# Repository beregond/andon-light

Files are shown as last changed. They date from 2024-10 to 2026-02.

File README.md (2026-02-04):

# ())))) Andon Light

Signal state with andon light!

## Docs

This document is not everything you need to know about this project, more info below in "More docs" section

> [!WARNING]
> This project is still in early development stage, so it may not work as expected.

> [!WARNING]
> If you experience lag during startup it means that either you don't have SD card inserted (with proper config) - and thats due to bug, or your power source is too weak (especially if you enable WiFi this may be the problem)

## How does it work?

Andon light is a tool for monitoring external device and signaling its state using lights and sounds.

> [!NOTE]
> Currently only configuration for TCS3472 sensor and Prusa mk4 is available. More configurations will be (hopefully) added in the future.

There are two basic components:

- **Device** - something we want to monitor, like 3d printer; state of device is read by sensor
- **System** - andon light itself.

Both of them have their statuses and below you can see how those statuses are mapped to patterns, colors and sounds.

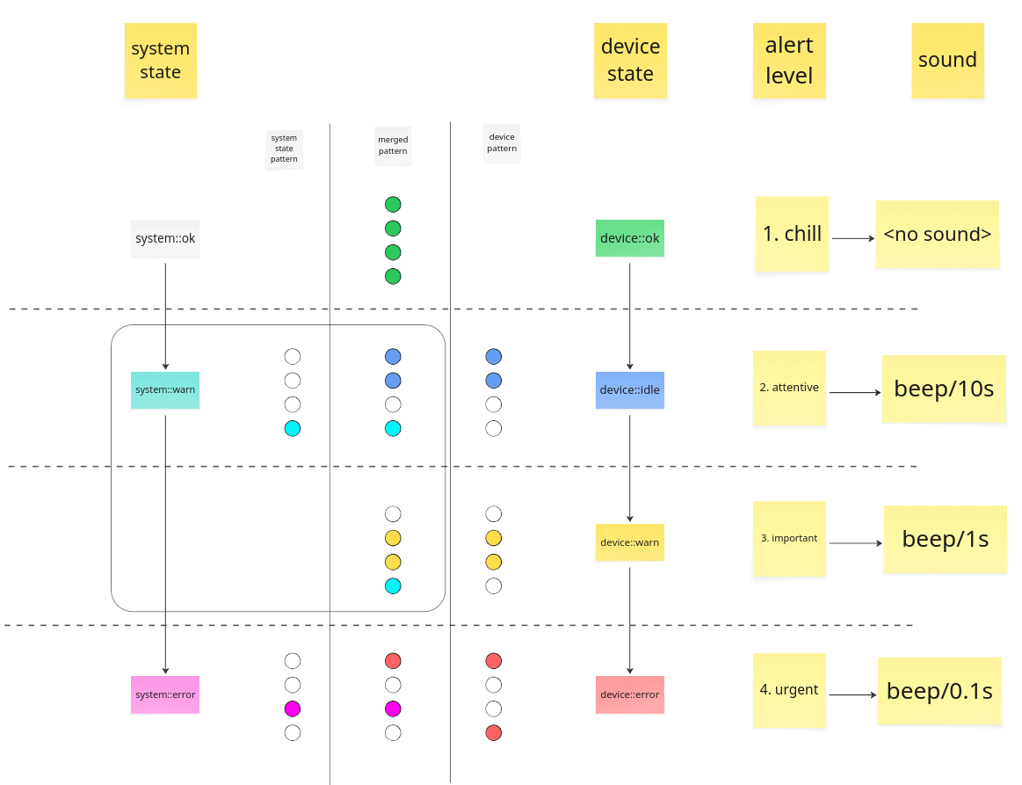
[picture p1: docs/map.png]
Patterns mapping


The algorithm works like this:

- Take the **highest** corresponding alert level from the **sensor and system state**
- Using patterns from that alert level, choose:
  - Pattern that matches both of the states
  - If no such pattern exists, choose the one that matches either of the states
- Choose sound that matches alert level

## Config

Store this in `andon.jso`. Currently there is no support for long file names (aka VFAT).

``` json
{
    "version": 0,
    "id": "my-3d-printer",
    "brightness": 10,
    "buzzer_enabled": true,

    "wifi_ssid": "your-ssid",
    "wifi_password": "your-password",

    "mqtt_host": "mqtt.example.com",
    "mqtt_port": 1883,
    "mqtt_username": "your-username",
    "mqtt_password": "your-password",
    "mqtt_device_type": "cnc",
    "mqtt_topic_prefix": "andon",
    "mqtt_topic": "your/custiom/topic"
}
```

### Config reference

- `id` - unique identifier of the device, it will default to `light-{MAC_ADDRESS}` if not set
- WiFi settings are optional, but required for MQTT
- MQTT section is optional, will work only with WiFi enabled
- `mqtt_username` - don't set for anonymous connection
- `mqtt_password` don't set for anonymous connection
- `mqtt_device_type` - `cnc` by default, used for mqtt topic construction, skipped if `mqtt_topic` is set
- `mqtt_topic_prefix` - `andon` by default, used for topic construction, skipped if `mqtt_topic` is set
- `mqtt_topic` - `null` by default, if not set - topic will be constructed using prefix, device type and id

## More docs

- To see the list of parts needed to build this project, check [this file](docs/parts.md).
- You will need few 3D printed parts, to print them follow [this guide](3d-models/readme.md).

## Development

List `devbin` dir to see available helpful commands

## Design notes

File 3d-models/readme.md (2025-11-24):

# 3d printed parts

**Use .step files as first choice**. All parts were printed with (Prusa MK4S printer and):

- standard black PLA
- 0.4mm nozzle
  - 0.15 layer height for shell in quality/structural mode (to print inner threads properly)
  - 0.2mm layer height for rest of parts (in speed mode)
- 15% infill (gyroid, but thats secondary)

Most of parts you should print in default orientation, unless stated otherwise. Below you can see extra settings for each part.

## Tower

Print it vertically. Supports are required, but avoid putting them in tight spaces inside (see picture below).

- [step](tower/tower.step)
- [3mf](tower/tower.3mf)
- [stl](tower/tower.stl)

Preview

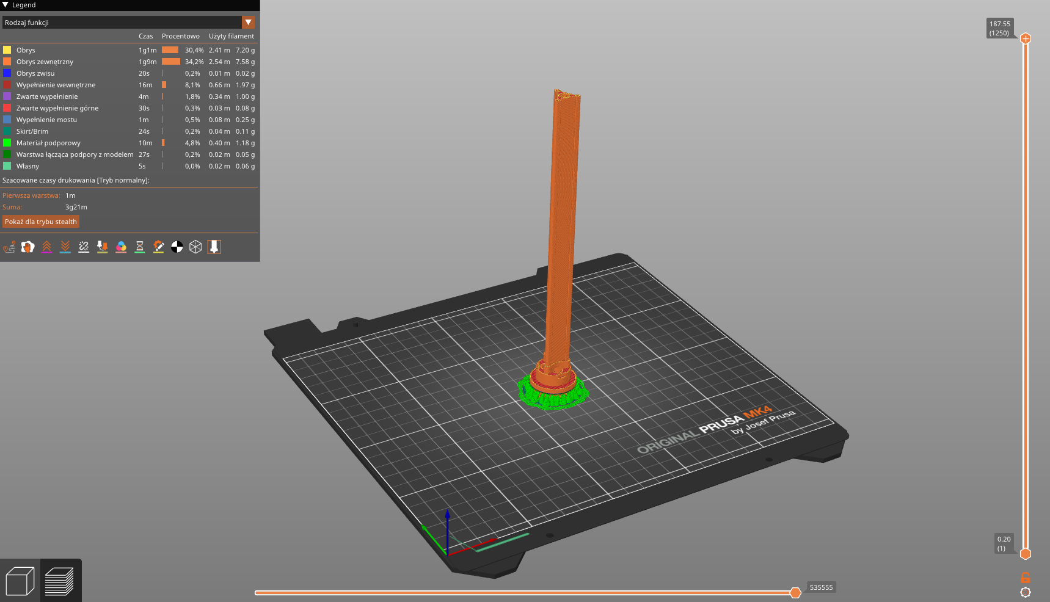
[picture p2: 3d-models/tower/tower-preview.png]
Tower print preview


### Where to avoid supports

You don't want to put supports between PCB holds and in the middle of the tower - only have them for flat overhangs outside and inside the tower.

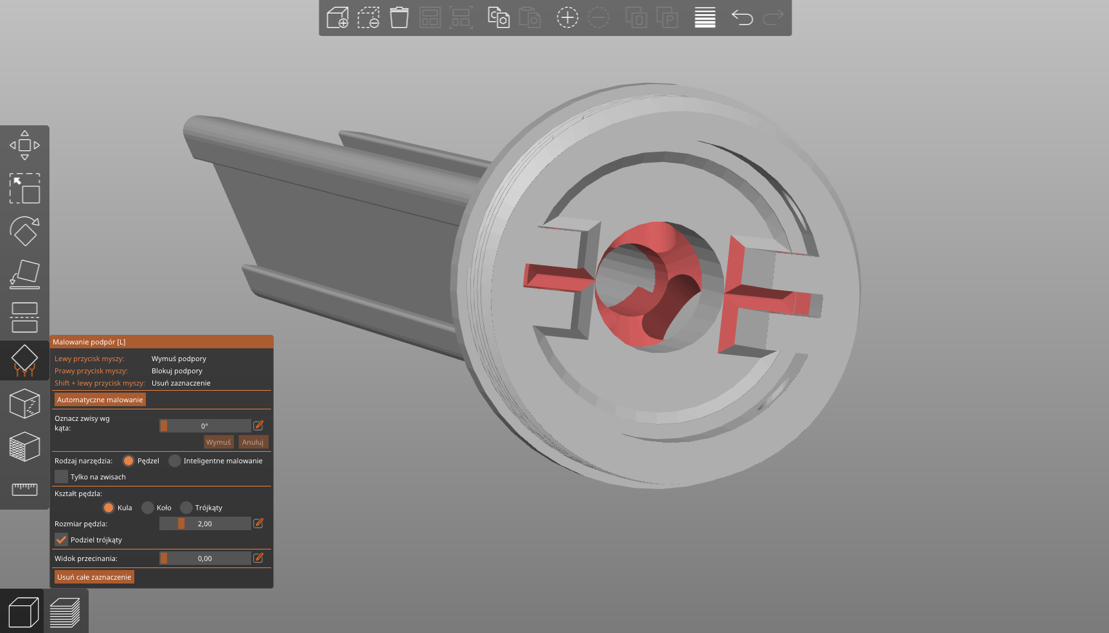
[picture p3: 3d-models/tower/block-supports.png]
Block supports


## Shell

Quality/structural mode is **required** to print threads properly (like 0.15 layer height in structural mode), 5mm inner brim is **recommended** (you can scrape it off with deburring tool easily).

- [step](shell/shell.step)
- [3mf](shell/shell.3mf)
- [stl](shell/shell.stl)

Preview

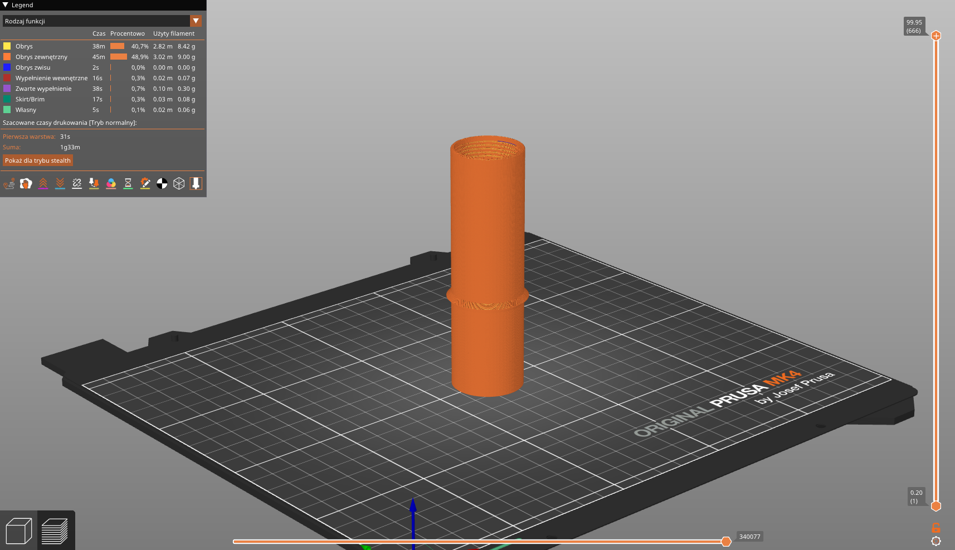
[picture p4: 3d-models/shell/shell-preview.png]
Shell print preview


## Hood

Print this part upside down, so you don't need supports.

- [step](hood/hood.step)
- [3mf](hood/hood.3mf)
- [stl](hood/hood.stl)

Preview

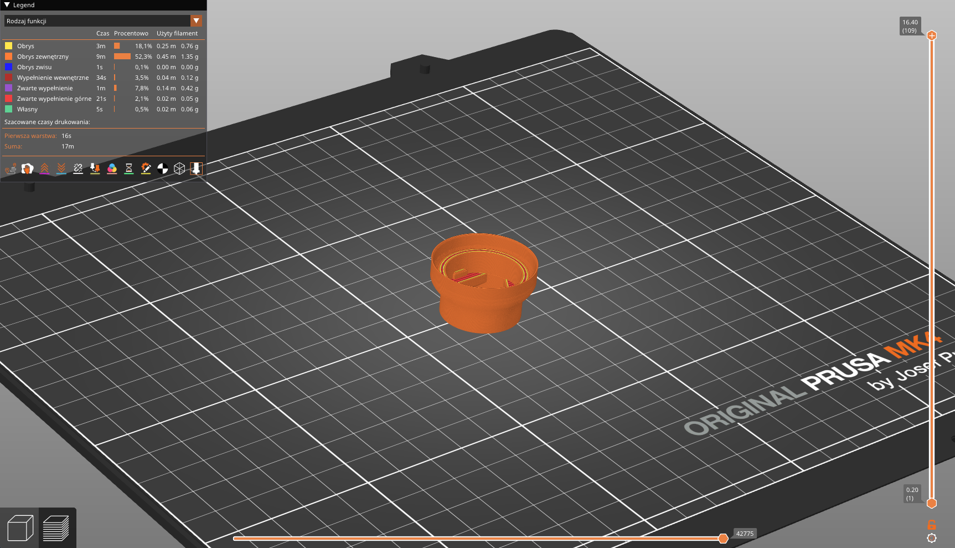
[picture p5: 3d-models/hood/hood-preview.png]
Hood print preview


## cap

Top cap for the tower. Print it with supports.

- [step](cap/cap.3mf)
- [3mf](cap/cap.3mf)
- [stl](cap/cap.stl)

Preview

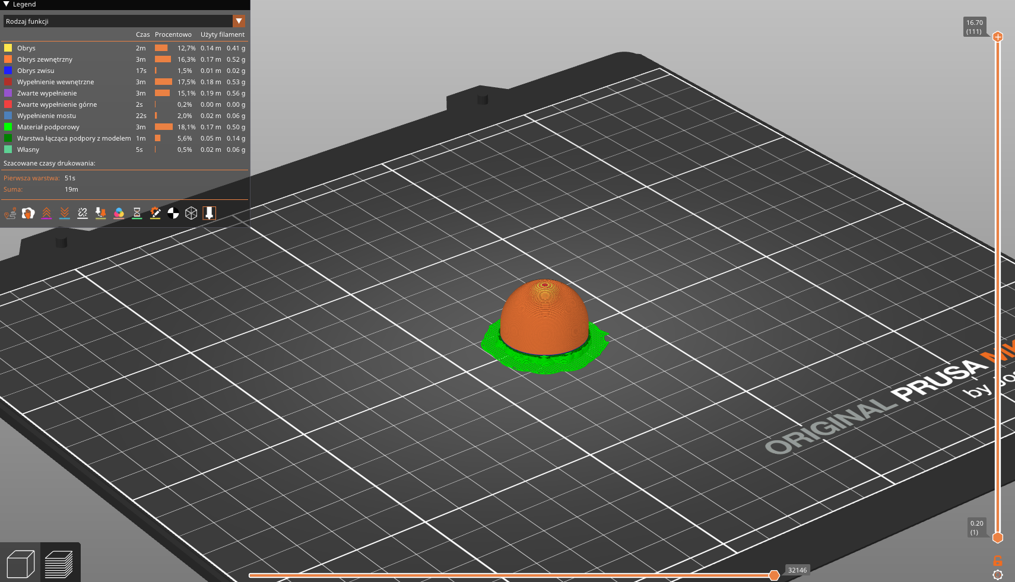
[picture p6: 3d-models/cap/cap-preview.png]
Cap print preview


## Bottom Cap

- [step](bottom-cap/bottom-cap.step)
- [3mf](bottom-cap/bottom-cap.3mf)
- [stl](bottom-cap/bottom-cap.stl)

Preview

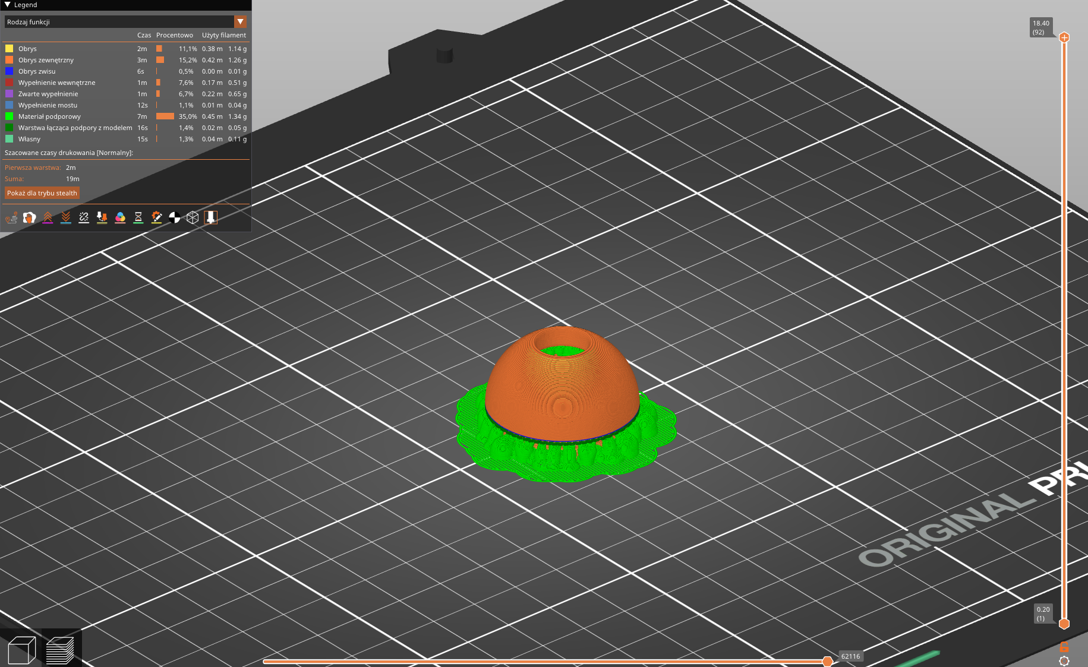
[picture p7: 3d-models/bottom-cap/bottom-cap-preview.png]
Bottom cap print preview


## Doughnut (aka holder)

Holder consist of three parts - "half" (of doughnut), "jam" and "half with hold" - you need to print all of them. No supports needed, just remember to print "half with hold" upside down.

> [!TIP]
> If you want to create your own holder - print "half" and "jam" - but create your own "half with hold" part. You can use "half.step" as a base and add your own design on top of it.

- Half
  - [step](doughnut/half.step)
  - [3mf](doughnut/half.3mf)
  - [stl](doughnut/half.stl)
- Jam
  - [step](doughnut/jam.step)
  - [3mf](doughnut/jam.3mf)
  - [stl](doughnut/jam.stl)
- Half with hold (print upside down)
  - [step](doughnut/half-with-hold.step)
  - [3mf](doughnut/half-with-hold.3mf)
  - [stl](doughnut/half-with-hold.stl)

"Half" preview

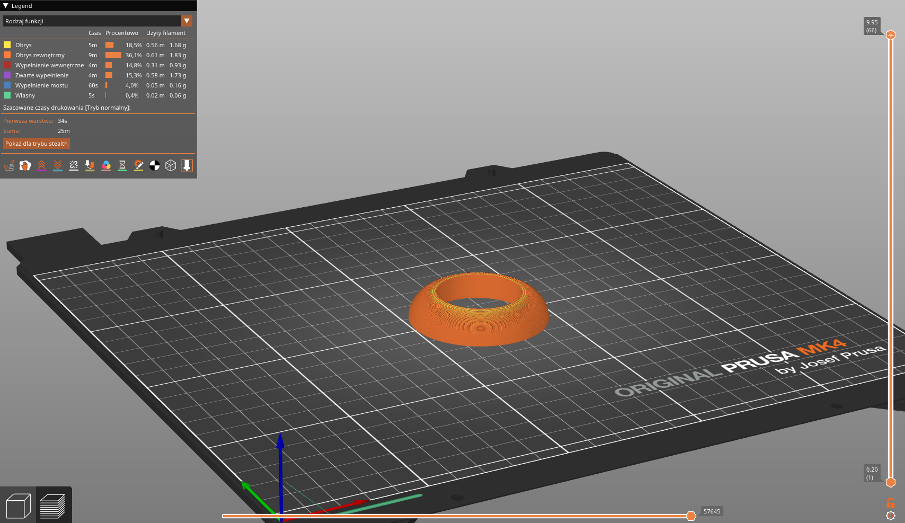
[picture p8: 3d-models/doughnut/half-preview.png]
Half print preview


"Jam" preview

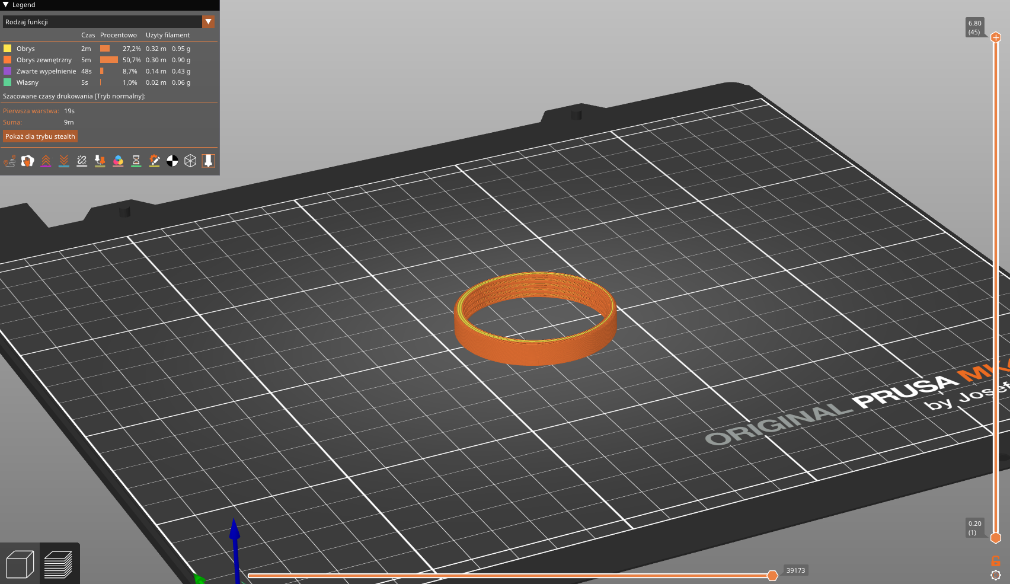
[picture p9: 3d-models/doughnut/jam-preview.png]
Jam print preview


"Half with hold" preview

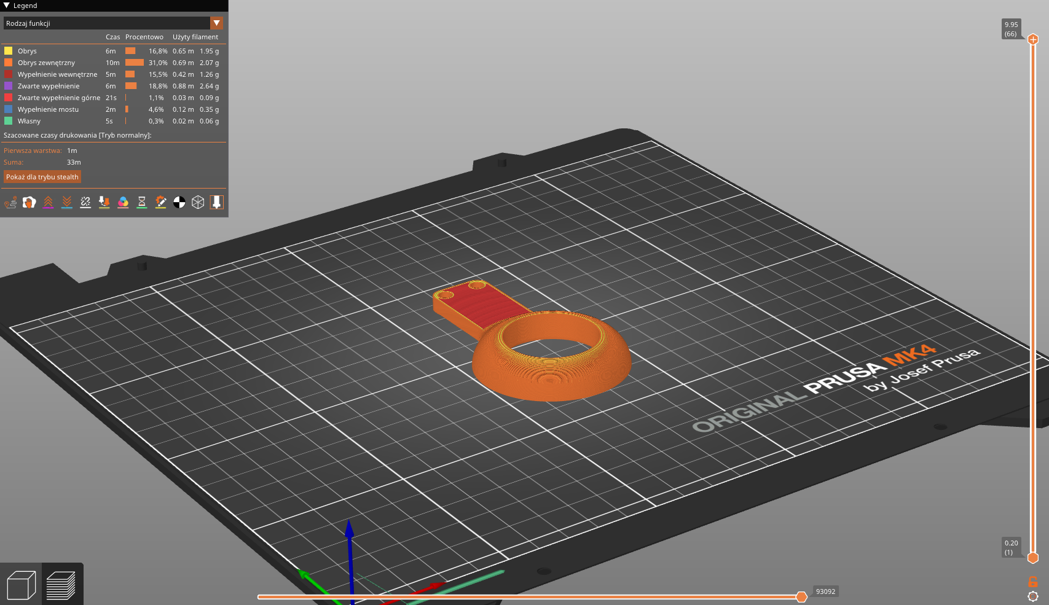
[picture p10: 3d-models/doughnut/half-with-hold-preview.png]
Half with hold print preview


## Junction box

> [!NOTE]
> Step file for junction box consist of all three sub parts - top, bottom and nut.

Print junction box with supports - they are needed to support threads halves.

- Junction box
  - Full step file - [step](junction-box/junction-box.step)
  - Bottom
    - [3mf](junction-box/junction-box-bottom.3mf)
    - [stl](junction-box/junction-box-bottom.stl)
  - Top
    - [3mf](junction-box/junction-box-top.3mf)
    - [stl](junction-box/junction-box-top.stl)
  - Nut
    - [3mf](junction-box/junction-box-nut.3mf)
    - [stl](junction-box/junction-box-nut.stl)

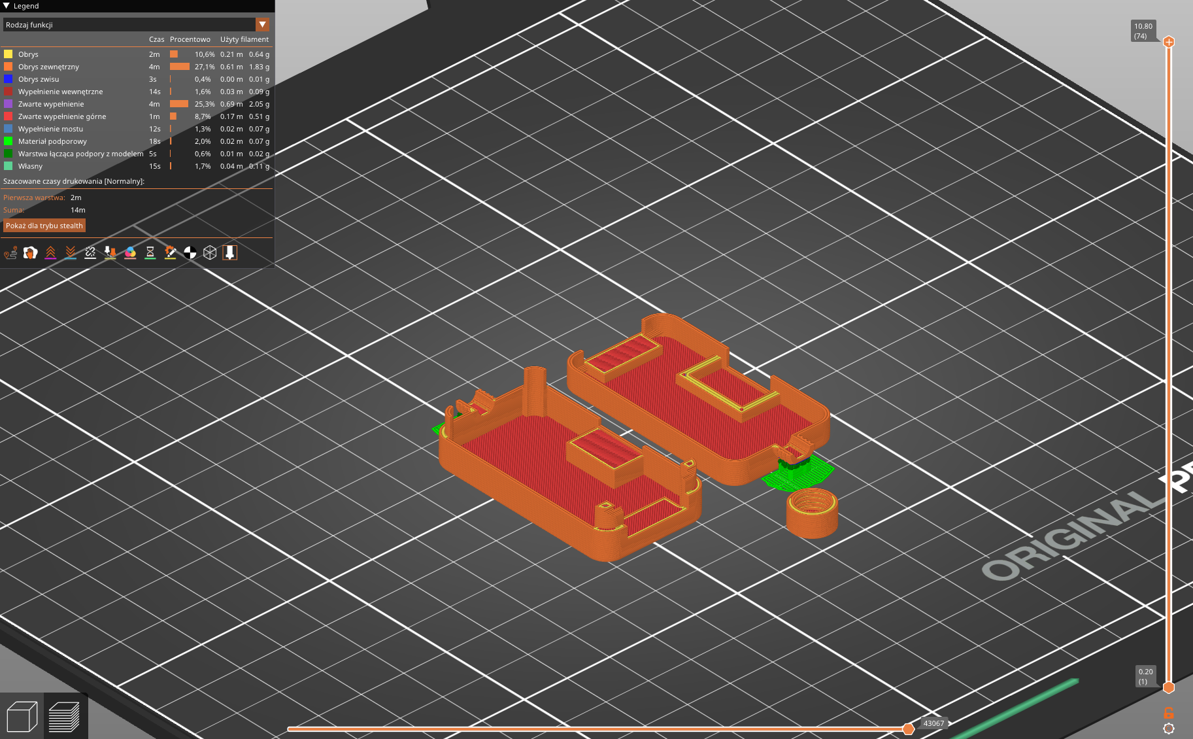
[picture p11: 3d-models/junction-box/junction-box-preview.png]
Junction box preview


Junction box holder is optional - but quite useful.

- Junction box holder
  - [step](junction-box/junction-box-holder.step)
  - [3mf](junction-box/junction-box-holder.3mf)
  - [stl](junction-box/junction-box-holder.stl)

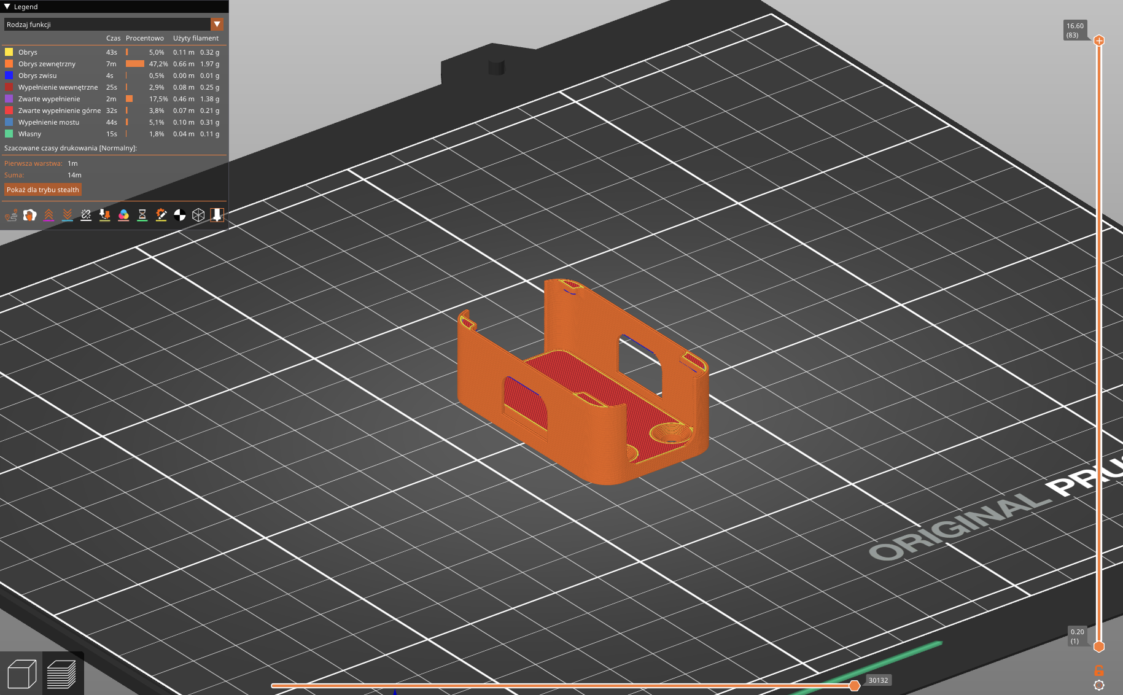
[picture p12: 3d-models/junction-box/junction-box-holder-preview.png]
Junction box holder preview


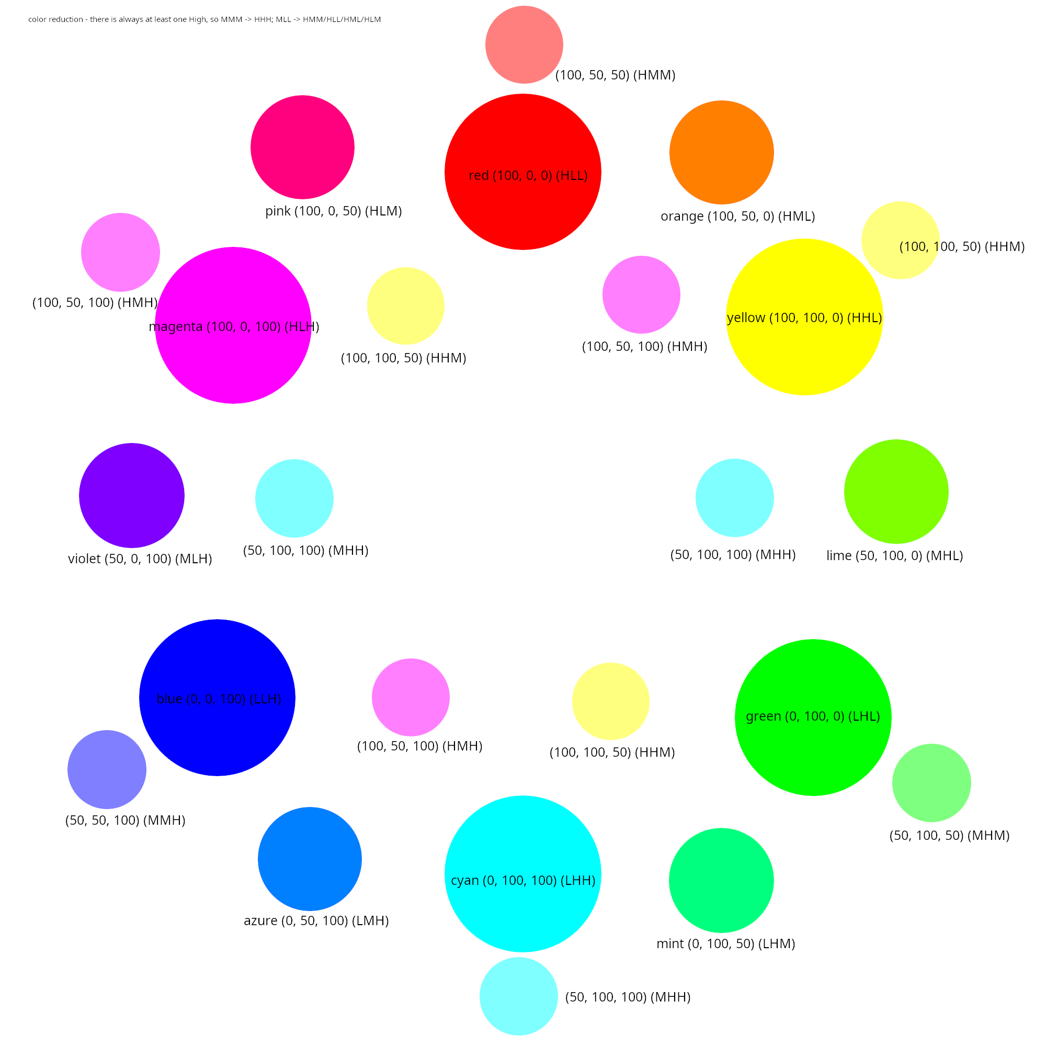
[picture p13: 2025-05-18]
core/andon-light-core/colors.png

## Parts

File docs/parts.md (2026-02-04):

# Parts list

- ESP32C3 (from Seed Studio XIAO provided witn antenna)
- Prototype board - 2x8 cm
- 3x stripe of 16 smart leds (WS2812B) - with density of 96 leds per meter
- SD card module (WH125 spi sd reader module)
- SD card
- USB-C cables:
  - one with angle plug for programming - because of lack of space
  - second one with straight plug for power supply
- USB charger
- USB-C charging port
- 2x 2k Ohm resistors
- PNP transistor (S8550)
- buzzer with generator - THT 12mm
- red THT LED (for heartbeat, so preferrably RED)
- TCS3472 sensor
- four pin socket and connector
- ceramic capacitors:
  - 1uF 50V
  - 10nF 50V
- Wire-To-Board Terminal Block (ARK connectors), 2.54 mm
  - 4 Ways - 2x
  - 3 Ways - 1x
- some 0.5mm^2 wire - it should be quite thin to make your life easier; you can harvest some from ethernet cable
- transparent plexiglass tube:
  - 20 mm outer diameter
  - 1 mm thickness
  - 18 mm inner diameter
  - 165 mm length
- toothpick

(To mount device first without soldering - also breadboard plus jumper wires are needed.)

## Wiring

- 5V <-> SD reader VCC, USB C port VCC, TSC3472 VIN, LED stripes anodes
- GND <-> SD reader GND, USB C port GND, TSC3472 GND, buzzer GND (-), red LED cathode, LED stripes cathodes (via transistor)
- 3V - not connected
- D10/GPIO10 (MOSI) <-> SD reader MOSI, LED stripes data in (via transistor)
- D9/GPIO9 (MISO) <-> SD reader MISO
- D8/GPIO8 (SCK) <-> SD reader SCK
- D6/GPIO21 - not connected
- D5/GPIO7 <-> TCS3472 SCL
- D4/GPIO6 <-> TCS3472 SDA
- D3/GPIO20 <-> "LED stripes transistor" base
- D2/GPIO4 <-> red LED anode
- D1/GPIO3 <-> buzzer anode (+)
- D0/GPIO2 <-> TCS3472 CS
- connect both capacitors between 5V and GND pins of ESP

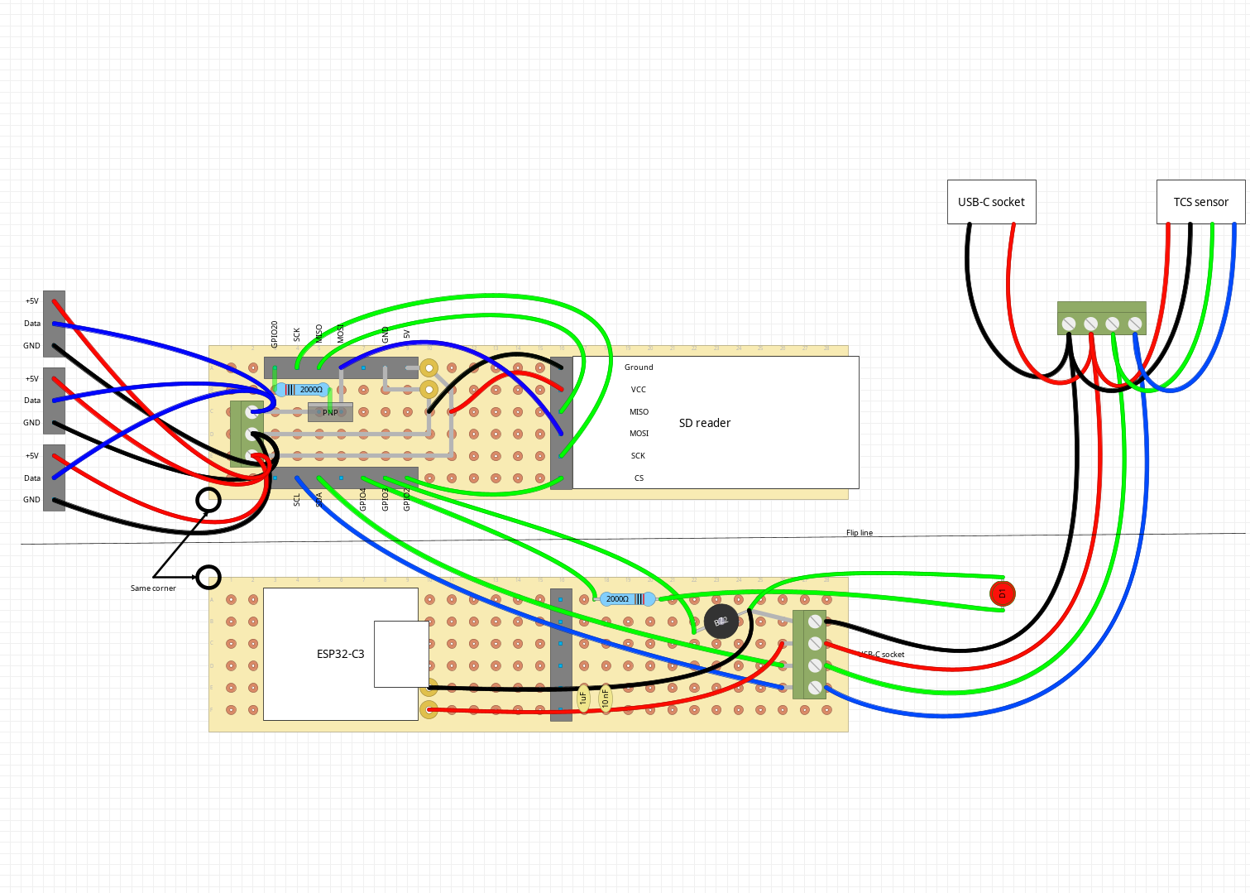
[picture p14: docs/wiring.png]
wiring


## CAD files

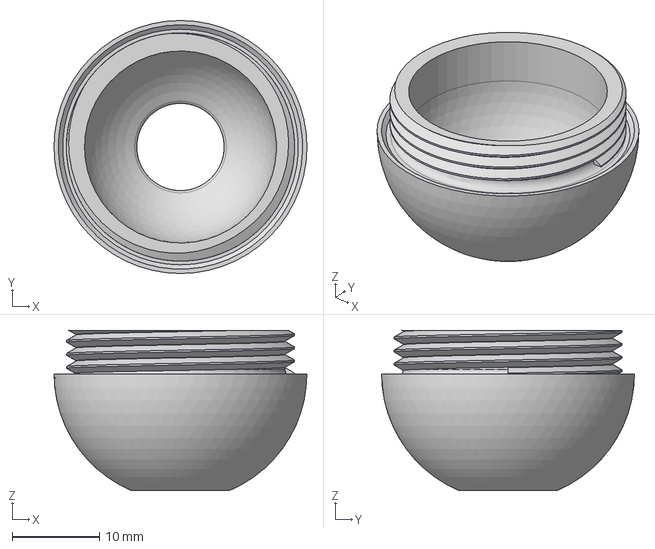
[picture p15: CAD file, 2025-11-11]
3d-models/bottom-cap/bottom-cap.step
29.0 x 29.0 x 18.4 mm

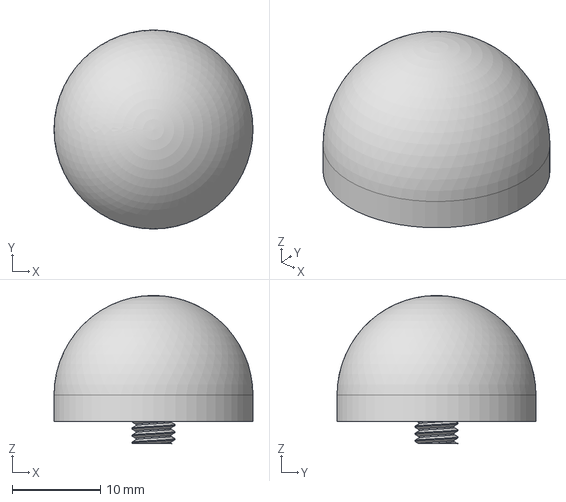
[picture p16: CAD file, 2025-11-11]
3d-models/cap/cap.step
22.5 x 22.5 x 16.8 mm

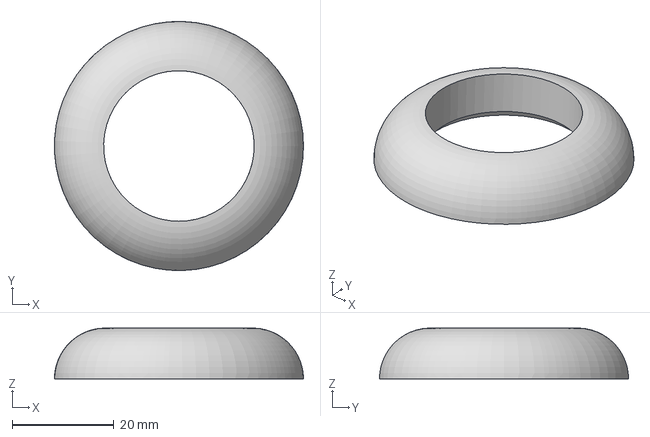
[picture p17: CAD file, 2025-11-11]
3d-models/doughnut/half.step
49.0 x 49.0 x 10.00 mm

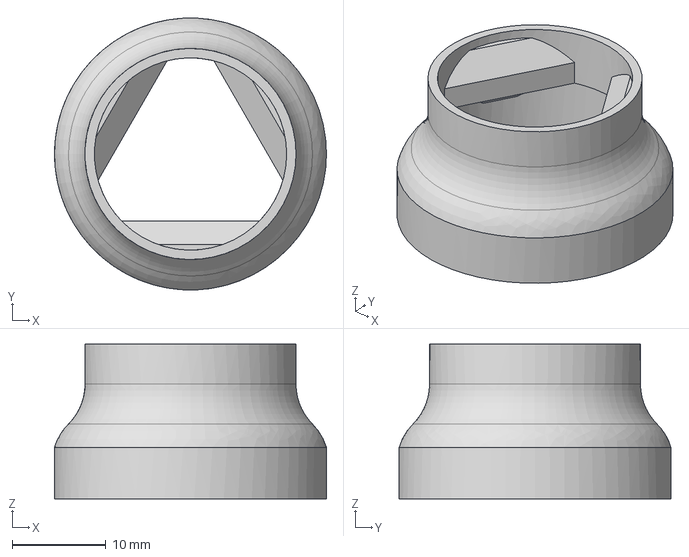
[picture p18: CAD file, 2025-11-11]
3d-models/hood/hood.step
29.0 x 29.0 x 16.5 mm

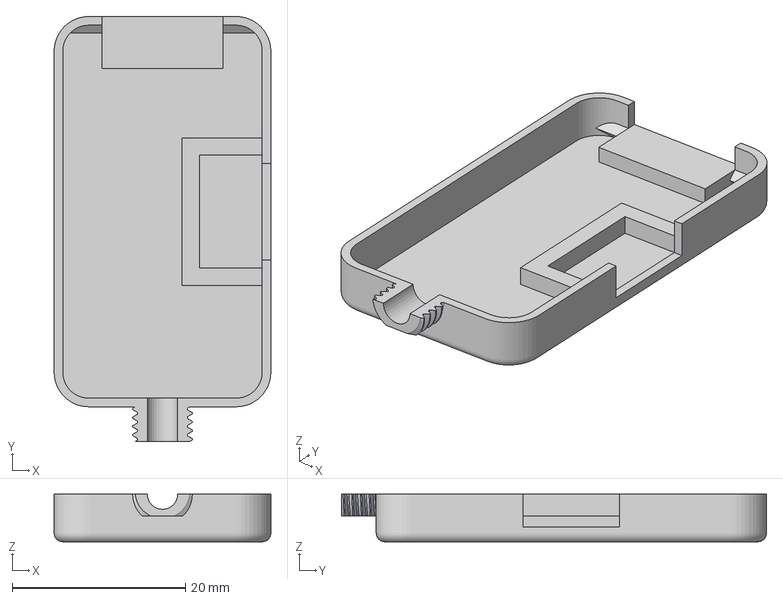
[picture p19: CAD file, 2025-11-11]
3d-models/junction-box/junction-box-bottom.3mf
25.0 x 49.0 x 5.50 mm

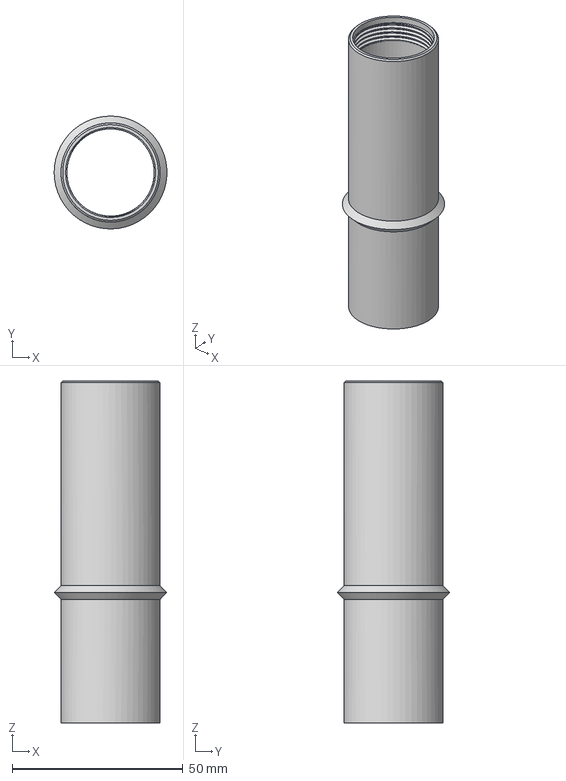
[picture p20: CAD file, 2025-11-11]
3d-models/shell/shell.step
33.0 x 33.0 x 100.0 mm

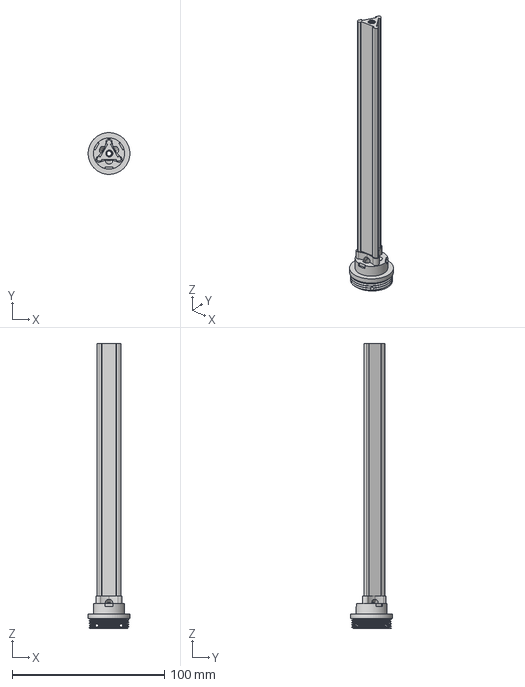
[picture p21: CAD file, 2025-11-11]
3d-models/tower/tower.step
27.5 x 27.5 x 187.5 mm

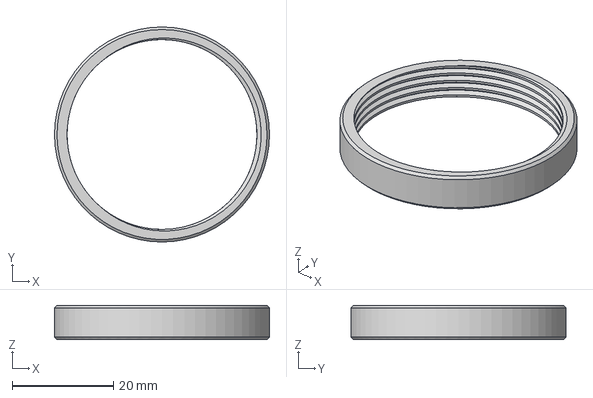
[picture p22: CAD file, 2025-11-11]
3d-models/doughnut/jam.step
42.5 x 42.5 x 6.80 mm

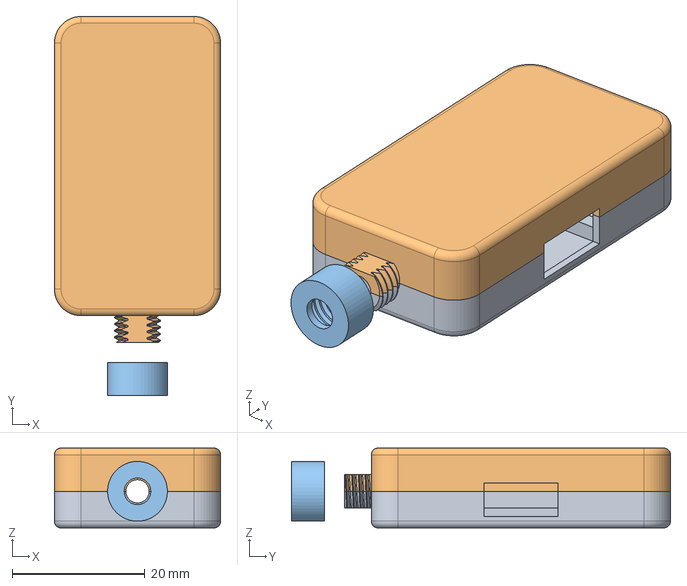
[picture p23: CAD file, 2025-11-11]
3d-models/junction-box/junction-box.step
25.0 x 57.0 x 12.0 mm

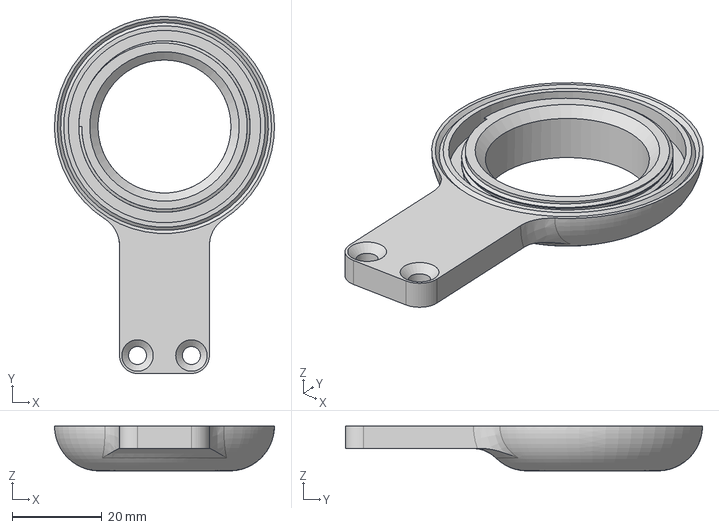
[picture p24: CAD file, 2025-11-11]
3d-models/doughnut/half-with-hold.step
49.0 x 79.5 x 10.00 mm

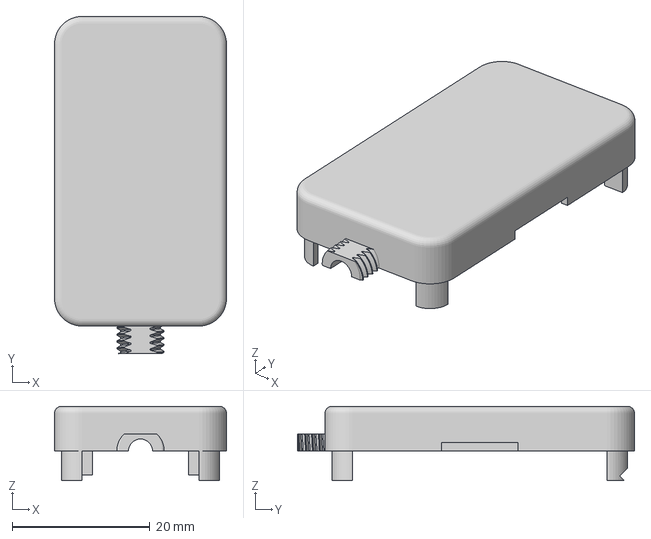
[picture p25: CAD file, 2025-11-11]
3d-models/junction-box/junction-box-top.3mf
25.0 x 49.0 x 10.8 mm

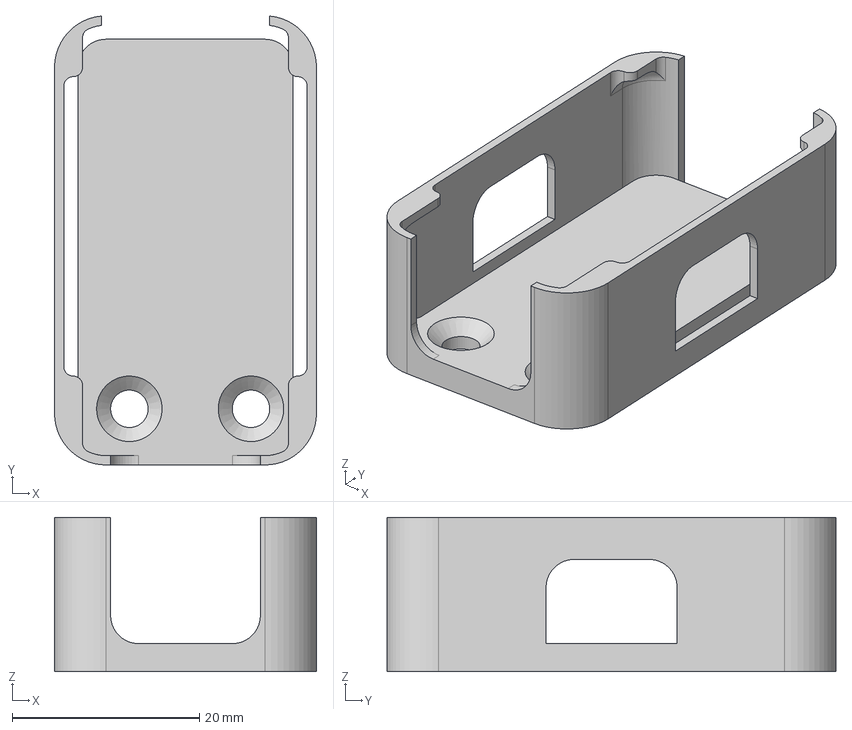
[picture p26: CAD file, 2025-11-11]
3d-models/junction-box/junction-box-holder.step
28.0 x 48.0 x 16.5 mm

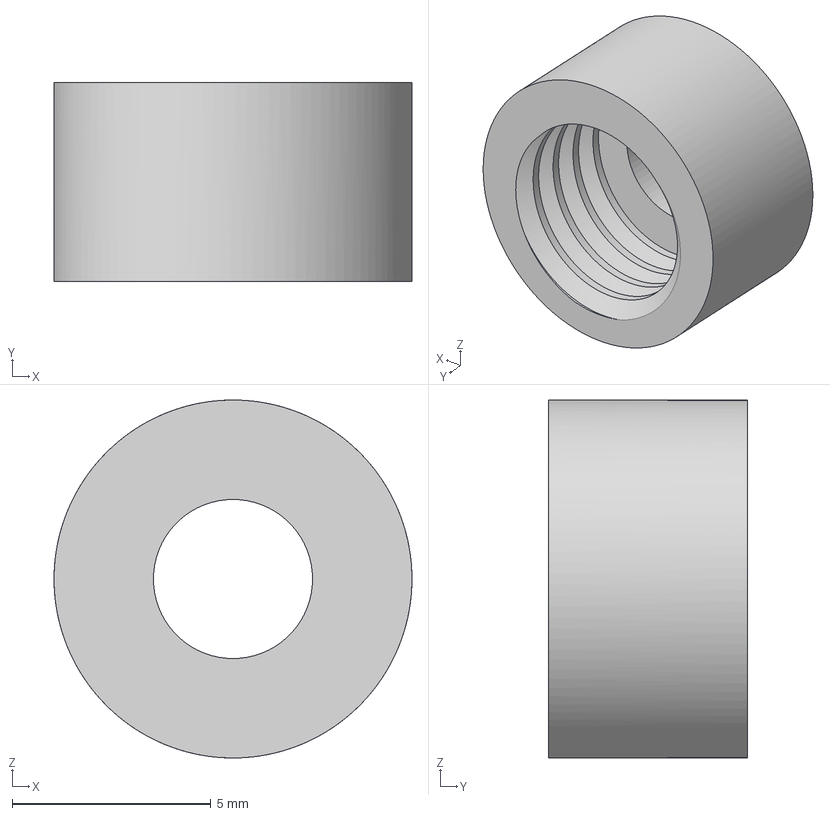
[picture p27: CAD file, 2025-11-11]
3d-models/junction-box/junction-box-nut.3mf
9.00 x 5.00 x 9.00 mm

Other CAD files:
3d-models/shell/shell.prusa-slicer-project.3mf
3d-models/bottom-cap/bottom-cap.3mf
3d-models/bottom-cap/bottom-cap.stl
3d-models/cap/cap.3mf
3d-models/cap/cap.stl
3d-models/doughnut/half-with-hold.3mf
3d-models/doughnut/half-with-hold.stl
3d-models/doughnut/half.3mf
3d-models/doughnut/half.stl
3d-models/doughnut/jam.3mf
3d-models/doughnut/jam.stl
3d-models/hood/hood.3mf
3d-models/hood/hood.stl
3d-models/junction-box/junction-box-bottom.stl
3d-models/junction-box/junction-box-holder.3mf
3d-models/junction-box/junction-box-holder.stl
3d-models/junction-box/junction-box-nut.stl
3d-models/junction-box/junction-box-top.stl
3d-models/shell/shell.3mf
3d-models/shell/shell.stl
3d-models/tower/tower.3mf
3d-models/tower/tower.stl

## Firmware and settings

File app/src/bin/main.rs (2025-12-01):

#![no_std]
#![no_main]

use andon_light::*;

use andon_light_core::{
    colors::{Color, ColorMapper},
    AlertLevel, DeviceState, ErrorCodesBase, SystemState,
};
use andon_light_macros::{default_from_env, ErrorCodesEnum};
use core::fmt::Write;
use embassy_embedded_hal::shared_bus::asynch::spi::SpiDevice;
use embassy_executor::Spawner;
use embassy_futures::select::select;
use embassy_net::{dns::DnsQueryType, tcp::TcpSocket};
use embassy_sync::{
    blocking_mutex::raw::{CriticalSectionRawMutex, NoopRawMutex},
    mutex::Mutex,
};
use embassy_time::{Duration, Ticker, Timer};
use embedded_hal_async::spi::SpiDevice as _;
use esp_backtrace as _;
use esp_hal::efuse::Efuse;
use esp_hal::interrupt::software::SoftwareInterruptControl;
use esp_hal::peripherals::GPIO3;
use esp_hal::timer::timg::TimerGroup;
use esp_hal::{
    clock::CpuClock,
    delay::Delay,
    dma::{DmaRxBuf, DmaTxBuf},
    dma_buffers,
    gpio::{DriveMode, Input, InputConfig, Level, Output, OutputConfig, Pull},
    i2c::master::I2c,
    ledc::{
        channel::{self, ChannelIFace},
        timer::{self, TimerIFace},
        LSGlobalClkSource, Ledc, LowSpeed,
    },
    rng::Rng,
    spi::{
        master::{Config, Spi, SpiDmaBus},
        Mode,
    },
    time::Rate,
    Async,
};
use esp_radio::wifi::{
    ClientConfig, ModeConfig, WifiController, WifiDevice, WifiEvent, WifiStaState,
};
use heapless::Vec;
use serde::{Deserialize, Serialize};
use static_cell::StaticCell;
use tcs3472::Tcs3472;
extern crate alloc;
use embassy_sync::signal::Signal;
use embassy_sync::watch::{Receiver, Sender, Watch};
use rust_mqtt::{
    client::client::MqttClient,
    client::client_config::{ClientConfig as MqttClientConfig, MqttVersion::MQTTv5},
    packet::v5::{publish_packet::QualityOfService::QoS1, reason_codes::ReasonCode},
    utils::rng_generator::CountingRng,
};

esp_bootloader_esp_idf::esp_app_desc!();

const VERSION: &str = env!("CARGO_PKG_VERSION");
const BUILD_VERSION: &str = env!("VERGEN_GIT_DESCRIBE");
const BUILD_TIME: &str = env!("VERGEN_BUILD_TIMESTAMP");

#[derive(Debug)]
pub enum WifiState {
    Disconnected,
    Connected,
}

const CONFIG_BUFFER_SIZE: usize = 4096;
const LEDS_AMOUNT: usize = default_from_env!(LEDS_AMOUNT, 16);
// Magic inside - see andon_light_core docs to understand why '* 12' is here
const MAX_SUPPORTED_LEDS: usize = default_from_env!(MAX_SUPPORTED_LEDS, 16) * 12;

#[inline]
const fn _empty_str() -> &'static str {
    ""
}

#[inline]
const fn _cnc() -> &'static str {
    "cnc"
}

#[inline]
const fn _andon() -> &'static str {
    "andon"
}

#[inline]
const fn _default_brightness() -> u8 {
    10
}

#[inline]
const fn _default_true() -> bool {
    true
}

#[inline]
const fn _default_version() -> u32 {
    1
}

#[inline]
const fn _default_mqtt_port() -> u16 {
    1883
}

#[inline]
fn andon_id() -> heapless::String<32> {
    let mac = Efuse::read_base_mac_address();
    let mut id = heapless::String::<32>::new();
    write!(id, "light-").unwrap();
    for chunk in mac {
        write!(id, "{:02X}", chunk).unwrap();
    }
    id
}

type SpiBus = Mutex<NoopRawMutex, SpiDmaBus<'static, Async>>;

#[derive(Debug, Hash, Eq, PartialEq, Clone, ErrorCodesEnum, Copy, Serialize)]
pub enum ErrorCodes {
    #[code(message = "Ok", level = "ok")]
    Ok,
    #[code(message = "Device is idle", level = "idle")]
    I001,
    #[code(message = "Device is turned off", level = "idle")]
    I002,
    #[code(message = "Device reports warning", level = "warn")]
    W001,
    #[code(message = "TCS sensor is unavailable", level = "system_error")]
    SE001,
    #[code(message = "WiFi disconnected", level = "system_warn")]
    SW001,
    #[code(message = "WiFi could not connect", level = "system_warn")]
    SW002,
    #[code(message = "MQTT config error", level = "system_warn")]
    SW003,
    #[code(message = "MQTT encountered DNS error", level = "system_warn")]
    SW004,
    #[code(message = "MQTT network connection error", level = "system_warn")]
    SW005,
    #[code(message = "MQTT connection to broker failed", level = "system_warn")]
    SW006,
    #[code(message = "MQTT couldn't send message", level = "system_warn")]
    SW007,
    #[code(message = "MQTT couldn't send ping", level = "system_warn")]
    SW008,
    #[code(message = "Failed to enable TCS sensor", level = "system_error")]
    SE002,
    #[code(message = "TCS sensor error", level = "system_error")]
    SE003,
    #[code(message = "Device reported error", level = "error")]
    E001,
    #[code(message = "No data from device", level = "error")]
    E002,
    #[code(message = "Device data too ambigous", level = "error")]
    E003,
}

type AndonLight = andon_light_core::AndonLight<
    ErrorCodes,
    { ErrorCodes::CODES_AMOUNT },
    { ErrorCodes::MIN_SET_SIZE },
    MAX_SUPPORTED_LEDS,
>;

// NOTE: this must be declared here for now, as IAT are in progress,
// check https://github.com/rust-lang/rust/issues/8995
type AndonReport = (
    SystemState,
    DeviceState,
    AlertLevel,
    heapless::Vec<ErrorCodes, { ErrorCodes::CODES_AMOUNT }>,
);

// One for buzzer, one for mqtt
const ANDON_REPORT_CHANNELS: usize = 2;
type AndonReporter = Watch<CriticalSectionRawMutex, AndonReport, ANDON_REPORT_CHANNELS>;
type AndonReporterSender =
    Sender<'static, CriticalSectionRawMutex, AndonReport, ANDON_REPORT_CHANNELS>;
type AndonReporterReceiver =
    Receiver<'static, CriticalSectionRawMutex, AndonReport, ANDON_REPORT_CHANNELS>;

// Onef for anon light runner, one for buzzer, one for mqtt
const ANDON_NOTIFIER_CHANNELS: usize = 3;
type AndonNotifier = Watch<CriticalSectionRawMutex, bool, ANDON_NOTIFIER_CHANNELS>;
type AndonNotifierSender = Sender<'static, CriticalSectionRawMutex, bool, ANDON_NOTIFIER_CHANNELS>;
type AndonNotifierReceiver =
    Receiver<'static, CriticalSectionRawMutex, bool, ANDON_NOTIFIER_CHANNELS>;

type WifiSignal = Signal<CriticalSectionRawMutex, WifiState>;
static ANDON_NOTIFIER: AndonNotifier = Watch::new();
static ANDON_REPORTER: AndonReporter = Watch::new();
static WIFI_SIGNAL: WifiSignal = Signal::new();

#[derive(Serialize, Deserialize, Debug, Clone)]
pub struct VersionProbe {
    version: u32,
}

#[derive(Serialize, Deserialize, Debug, Clone)]
struct DeviceConfig {
    // Maybe use string for version in future?
    #[serde(default = "_default_version")]
    version: u32,
    #[serde(default = "_empty_str")]
    id: &'static str,
    #[serde(default = "_default_true")]
    buzzer_enabled: bool,
    #[serde(default = "_default_brightness")]
    brightness: u8,
    #[serde(default = "_empty_str")]
    wifi_ssid: &'static str,
    #[serde(default = "_empty_str")]
    wifi_password: &'static str,
    #[serde(default = "_empty_str")]
    mqtt_host: &'static str,
    #[serde(default = "_default_mqtt_port")]
    mqtt_port: u16,
    #[serde(default = "_empty_str")]
    mqtt_username: &'static str,
    #[serde(default = "_empty_str")]
    mqtt_password: &'static str,
    #[serde(default = "_cnc")]
    mqtt_device_type: &'static str,
    #[serde(default = "_andon")]
    mqtt_topic_prefix: &'static str,
    #[serde(default = "_empty_str")]
    mqtt_topic: &'static str,
}

impl Default for DeviceConfig {
    fn default() -> Self {
        serde_json_core::de::from_slice(b"{}").unwrap().0
    }
}

impl DeviceConfig {
    pub fn generate_andon_config(&self) -> andon_light_core::Config {
        andon_light_core::Config::new(LEDS_AMOUNT as u8, self.brightness)
    }
}

struct Device {
    config: DeviceConfig,
    andon_light: AndonLight,
}

impl Device {
    pub fn new(device_config: DeviceConfig) -> Self {
        let andon_light = AndonLight::new(device_config.generate_andon_config());
        Self {
            config: device_config,
            andon_light,
        }
    }
}

type DeviceAsyncMutex = Mutex<CriticalSectionRawMutex, Device>;

macro_rules! notify {
    ($device:expr, $error_code:expr) => {{
        let mut device = $device.lock().await;
        device.andon_light.notify($error_code);
    }};
}
macro_rules! resolve {
    ($device:expr, $error_code:expr) => {{
        let mut device = $device.lock().await;
        device.andon_light.resolve($error_code);
    }};
}

#[embassy_executor::task]
async fn run_andon_light(
    mut spi: SpiDevice<'static, NoopRawMutex, SpiDmaBus<'static, Async>, Output<'static>>,
    device: &'static DeviceAsyncMutex,
    mut andon_notifier: AndonNotifierReceiver,
) {
    log::debug!("Start of led test procedure");

    let test_patterns;
    let pause: u64 = 150;

    {
        let mut device = device.lock().await;
        test_patterns = device.andon_light.generate_test_patterns();
    }
    for pattern in test_patterns {
        spi.write(pattern.as_slice()).await.unwrap();
        Timer::after(Duration::from_millis(pause)).await;
    }
    Timer::after(Duration::from_millis(pause)).await;
    log::debug!("End of test procedure");

    log::debug!("Entering regular leds cycle");
    loop {
        let pattern;
        {
            let mut device = device.lock().await;
            pattern = device.andon_light.generate_signal();
        }
        spi.write(pattern.as_slice()).await.unwrap();
        select(
            Timer::after(Duration::from_secs(10)),
            andon_notifier.changed(),
        )
        .await;
    }
}

#[embassy_executor::task]
async fn heartbeat(
    mut lstimer: timer::Timer<'static, LowSpeed>,
    mut channel: channel::Channel<'static, LowSpeed>,
) {
    log::debug!("Heartbeat task started");
    lstimer
        .configure(timer::config::Config {
            duty: timer::config::Duty::Duty5Bit,
            clock_source: timer::LSClockSource::APBClk,
            frequency: Rate::from_khz(24),
        })
        .unwrap();

    channel
        .configure(channel::config::Config {
            timer: &lstimer,
            duty_pct: 10,
            drive_mode: DriveMode::PushPull,
        })
        .unwrap();

    loop {
        channel.start_duty_fade(30, 90, 100).unwrap();
        Timer::after(Duration::from_millis(100)).await;
        channel.start_duty_fade(90, 10, 100).unwrap();
        Timer::after(Duration::from_millis(100)).await;
        channel.start_duty_fade(10, 30, 100).unwrap();
        Timer::after(Duration::from_millis(800)).await;
    }
}

/// Checks for alert level changes and signals to other peripherals,
/// so they can react accordingly
#[embassy_executor::task]
async fn andon_supervisor(
    device: &'static DeviceAsyncMutex,
    notifier: AndonNotifierSender,
    reporter: AndonReporterSender,
) {
    let mut ticker = Ticker::every(Duration::from_millis(500));
    let mut current_report;
    {
        let device = device.lock().await;
        current_report = device.andon_light.get_report()
    }
    loop {
        let report;
        {
            let device = device.lock().await;
            report = device.andon_light.get_report();
        }
        if current_report != report {
            reporter.send(report.clone());
            notifier.send(true);
            current_report = report;
        }
        ticker.next().await;
    }
}
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
async fn main(spawner: Spawner) {
    esp_println::logger::init_logger_from_env();
    log::info!("Hello world!");
    log::info!("Andon Light firmware version: {}", BUILD_VERSION);
    log::info!("Build timestamp: {}", BUILD_TIME);

    let config = esp_hal::Config::default().with_cpu_clock(CpuClock::max());
    let peripherals = esp_hal::init(config);

    esp_alloc::heap_allocator!(size: 72 * 1024);

    let timg0 = TimerGroup::new(peripherals.TIMG0);
    let software_interrupt = SoftwareInterruptControl::new(peripherals.SW_INTERRUPT);
    esp_rtos::start(timg0.timer0, software_interrupt.software_interrupt0);

    log::info!("Embassy initialized!");

    // Configure the LEDC
    let mut ledc = Ledc::new(peripherals.LEDC);
    ledc.set_global_slow_clock(LSGlobalClkSource::APBClk);

    // Heartbeat
    let heartbeat_led = peripherals.GPIO4;
    let lstimer0 = ledc.timer::<LowSpeed>(timer::Number::Timer0);
    let channel0 = ledc.channel(channel::Number::Channel0, heartbeat_led);
    spawner.spawn(heartbeat(lstimer0, channel0)).unwrap();

    // Define Spi
    let sclk = Output::new(peripherals.GPIO8, Level::Low, OutputConfig::default());
    let miso = Input::new(
        peripherals.GPIO9,
        InputConfig::default().with_pull(Pull::None),
    );
    let mosi = Output::new(peripherals.GPIO10, Level::Low, OutputConfig::default());

    #[allow(clippy::manual_div_ceil)]
    let (rx_buffer, rx_descriptors, tx_buffer, tx_descriptors) = dma_buffers!(32000);
    let dma_rx_buf = DmaRxBuf::new(rx_descriptors, rx_buffer).unwrap();
    let dma_tx_buf = DmaTxBuf::new(tx_descriptors, tx_buffer).unwrap();

    let spi = Spi::new(
        peripherals.SPI2,
        Config::default()
            .with_frequency(Rate::from_mhz(4))
            .with_mode(Mode::_0),
    )
    .unwrap()
    .with_sck(sclk)
    .with_mosi(mosi)
    .with_miso(miso)
    .with_dma(peripherals.DMA_CH0)
    .with_buffers(dma_rx_buf, dma_tx_buf)
    .into_async();

    static SPI_BUS: StaticCell<SpiBus> = StaticCell::new();
    let spi_bus = SPI_BUS.init(Mutex::new(spi));

    log::debug!("Peripherals initialized");
    log::debug!("Reading config from SD card");

    static BUFFER: StaticCell<[u8; CONFIG_BUFFER_SIZE]> = StaticCell::new();
    let buffer = BUFFER.init([0u8; CONFIG_BUFFER_SIZE]);
    let sd_select = Output::new(peripherals.GPIO2, Level::High, OutputConfig::default());
    let sd_reader = SdReader::new(spi_bus, sd_select, Delay::new());
    // TODO: Need better support for filesystem and config errors
    let result = sd_reader.read_config("CONFIG.JSO", buffer).await;

    let mut app_config = match result {
        Ok(num_read) => {
            // For now only checking version, but in future it may be used to check compatibility
            match serde_json_core::de::from_slice::<VersionProbe>(&buffer[0..num_read]) {
                Ok((result, _)) => {
                    log::info!("Version read properly from file: {}", result.version);
                }
                _ => {
                    log::info!("Seems there is no version in config file, falling back to default");
                }
            }

            match serde_json_core::de::from_slice::<DeviceConfig>(&buffer[0..num_read]) {
                Ok((result, _)) => {
                    log::debug!("Config read properly from file");
                    result
                }
                Err(e) => {
                    log::warn!("Seems there is no config file, falling back to default");
                    log::warn!("{e:?}");
                    DeviceConfig::default()
                }
            }
        }
        Err(e) => {
            log::warn!("Failed to read config file");
            log::warn!("{e:?}");
            DeviceConfig::default()
        }
    };

    if app_config.id.is_empty() {
        static ID_BUFFER: StaticCell<heapless::String<32>> = StaticCell::new();
        app_config.id = ID_BUFFER.init(andon_id());
    }

    log::debug!("End of config read");
    log::info!("Andon light ID: {}", app_config.id);

    log::debug!("Starting up leds control");

    let leds_select = Output::new(peripherals.GPIO20, Level::Low, OutputConfig::default());
    let spi_dev = SpiDevice::new(spi_bus, leds_select);

    static ANDON: StaticCell<DeviceAsyncMutex> = StaticCell::new();

    let notifier = ANDON_NOTIFIER.sender();
    let reporter = ANDON_REPORTER.sender();
    let device = ANDON.init(Mutex::new(Device::new(app_config)));
    spawner
        .spawn(run_andon_light(
            spi_dev,
            device,
            ANDON_NOTIFIER.receiver().unwrap(),
        ))
        .unwrap();

    log::debug!("Leds started");

    spawner
        .spawn(andon_supervisor(device, notifier, reporter))
        .unwrap();

    {
        let andon = device.lock().await;
        if andon.config.buzzer_enabled {
            log::debug!("Buzzer enabled");
            let buzzer_pin = peripherals.GPIO3;
            spawner
                .spawn(buzzer(
                    buzzer_pin,
                    ledc,
                    device,
                    ANDON_NOTIFIER.receiver().unwrap(),
                    ANDON_REPORTER.receiver().unwrap(),
                ))
                .unwrap();
        } else {
            log::debug!("Buzzer is disabled");
        }
    }

    let i2c = I2c::new(peripherals.I2C0, esp_hal::i2c::master::Config::default())
        .unwrap()
        .with_sda(peripherals.GPIO6)
        .with_scl(peripherals.GPIO7)
        .into_async();
    let sensor = Tcs3472::new(i2c);
    spawner.spawn(rgb_probe_task(sensor, device)).unwrap();

    // Initialization of wifi
    {
        let andon = device.lock().await;
        if !andon.config.wifi_ssid.is_empty() && !andon.config.wifi_password.is_empty() {
            static NET_RESOURCES: StaticCell<esp_radio::Controller> = StaticCell::new();
            log::info!("Connecting to WiFi SSID: {}", andon.config.wifi_ssid);
            let esp_radio_ctrl = NET_RESOURCES.init(esp_radio::init().unwrap());

            // We must initialize some kind of interface and start it.
            let (controller, interfaces) =
                esp_radio::wifi::new(esp_radio_ctrl, peripherals.WIFI, Default::default()).unwrap();

            let wifi_interface = interfaces.sta;
            let config = embassy_net::Config::dhcpv4(Default::default());
            let rng = Rng::new();
            let seed = (rng.random() as u64) << 32 | rng.random() as u64;

            // Init network stack
            static RESOURCES: StaticCell<embassy_net::StackResources<5>> = StaticCell::new();
            let (stack, runner) = embassy_net::new(
                wifi_interface,
                config,
                RESOURCES.init(embassy_net::StackResources::new()),
                seed,
            );

            let mode_config = ModeConfig::Client(
                ClientConfig::default()
                    .with_ssid(andon.config.wifi_ssid.into())
                    .with_password(andon.config.wifi_password.into()),
            );

            spawner.spawn(net_task(runner)).ok();
            spawner
                .spawn(connection(
                    controller,
                    device,
                    stack,
                    mode_config,
                    &WIFI_SIGNAL,
                ))
                .ok();

            if !andon.config.mqtt_host.is_empty() {
                spawner
                    .spawn(mqtt_publisher(
                        device,
                        stack,
                        &WIFI_SIGNAL,
                        ANDON_NOTIFIER.receiver().unwrap(),
                        ANDON_REPORTER.receiver().unwrap(),
                    ))
                    .ok();
            } else {
                log::info!("MQTT host is empty, skipping MQTT initialization");
            }
        } else {
            log::info!("WiFi SSID or password is empty, skipping WiFi initialization, skipping MQTT initialization");
        }
    }
}
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

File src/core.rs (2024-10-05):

use embassy_time::{Duration, Timer};

pub trait OutputSpiDevice<Word: Copy + 'static = u8> {
    type Error: core::fmt::Debug;
    async fn write(&mut self, buf: &[Word]) -> Result<(), Self::Error>;
}

#[derive(Debug, Clone, Copy)]
pub struct Color {
    /// Red
    pub r: u8,
    /// Green
    pub g: u8,
    /// Blue
    pub b: u8,
}

enum DeviceState {
    Ok,    // I don't have to do anything, the system is running
    Idle,  // the system is idle, I may have to do something, but I don't have to do it now
    Warn,  // I should do something, but it's not urgent
    Error, // I have to do something now
}

enum SystemState {
    Ok,
    Warn,
    Error,
}

pub struct AndonLight {
    device_state: DeviceState,
    system_state: SystemState,
    leds_amount: u8,
    speed: u16,
}

impl AndonLight {
    pub fn new(leds_amount: u8, speed: u16) -> Self {
        Self {
            device_state: DeviceState::Ok,
            system_state: SystemState::Ok,
            leds_amount,
            speed,
        }
    }

    pub async fn run_test_procedure(&mut self, mut device: impl OutputSpiDevice) {
        let green = Color { r: 0, g: 16, b: 0 };
        let red = Color { r: 16, g: 0, b: 0 };
        let blue = Color { r: 0, g: 0, b: 16 };
        let empty = Color { r: 0, g: 0, b: 0 };
        let white = Color { r: 8, g: 8, b: 8 };

        let send = [[empty; 16], [red; 16], [green; 16], [blue; 16]];

        let send2 = [
            [empty; 16],
            [
                white, white, empty, empty, white, white, empty, empty, white, white, empty, empty,
                white, white, empty, empty,
            ],
            [
                empty, white, white, empty, empty, white, white, empty, empty, white, white, empty,
                empty, white, white, empty,
            ],
            [
                empty, empty, white, white, empty, empty, white, white, empty, empty, white, white,
                empty, empty, white, white,
            ],
        ];

        loop {
            for row in send.iter() {
                for color in row.iter() {
                    self.send_color(&mut device, color).await;
                }
                Timer::after(Duration::from_millis(self.speed as u64)).await;
            }
            for row in send2.iter() {
                for color in row.iter() {
                    self.send_color(&mut device, color).await;
                }
                Timer::after(Duration::from_millis(self.speed as u64)).await;
            }
        }
    }

    async fn send_color<'a>(&mut self, spi: &mut impl OutputSpiDevice, color: &Color) {
        // Priming spi as it eats first byte ¯\_(ツ)_/¯
        spi.write(&[0b0]).await.unwrap();
        let data = to_bytes(color.g);
        spi.write(&data).await.unwrap();
        let data = to_bytes(color.r);
        spi.write(&data).await.unwrap();
        let data = to_bytes(color.b);
        spi.write(&data).await.unwrap();
    }
}

fn to_bytes(mut data: u8) -> [u8; 4] {
    // This function is copied from smart-leds crate.
    //
    // Send two bits in one spi byte. High time first, then the low time
    // The maximum for T0H is 500ns, the minimum for one bit 1063 ns.
    // These result in the upper and lower spi frequency limits
    let mut result = [0b0; 4];
    let patterns = [0b1000_1000, 0b1000_1110, 0b11101000, 0b11101110];
    for item in result.iter_mut() {
        let bits = (data & 0b1100_0000) >> 6;
        *item = patterns[bits as usize];
        data <<= 2;
    }
    result
}

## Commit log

2024-10-02 Use shared spi bus
2024-12-01 Add sd reader at common SPI
2024-12-07 Add partitions table
    [partitions.csv]
2024-12-31 Move probe check to task
2025-01-04 Send error codes to andon
    [lib.rs, main.rs]
2025-01-11 Added ok code, added led reset
    [lib.rs, main.rs]
2025-04-11 Add heartbeat diode task
2025-04-21 Draft of buzzer sounds
    [lib.rs, main.rs]
2025-04-21 Couple buzzer with andon state
    [main.rs]
2025-05-17 Reorganization - intro for testing
    [partitions.csv]
2025-05-18 Switch to new logic
2025-05-19 Change color schema to match prusa printer
2025-05-22 Add first models
    [plug.3mf, plug.stl, tower.3mf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]
2025-05-22 Fix linking
    [plug.3mf, plug.stl, tower.3mf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]
2025-05-22 Add other 3d parts
    [bottom_cap.3mf, bottom_cap.prusa-slicer-project.3mf, bottom_cap.stl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]
2025-05-22 Fix file names
    [bottom-cap.3mf, bottom-cap.prusa-slicer-project.3mf, bottom-cap.stl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]
2025-05-27 Add wifi info printing
2025-07-20 Add wiring
2025-07-22 Add wiring docs
2025-07-26 Fix wiring
2025-10-25 Switch to non blocking tcp stack
2025-10-27 Add device_id
2025-11-04 Unify supervisors, fix some bugs
    [lib.rs, main.rs]
2025-11-11 Update parts readme
    [bottom cap.3mf, bottom cap.step, bottom-cap.3mf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]
2025-11-11 Fix names
    [bottom-cap.3mf, bottom-cap.step]
2025-11-13 Remove led reset function
    [main.rs]
2025-11-13 Update wiring, change led stripes gpio select
2025-11-14 Remove leds amount as config option
2025-11-29 Improve wiring map
2025-12-01 Fix clearing error code for no color detected
    [main.rs]
2026-02-04 Add capacitors to project
2026-02-04 Update wiring
